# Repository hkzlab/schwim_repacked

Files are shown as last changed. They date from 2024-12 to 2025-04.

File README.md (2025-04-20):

# SCHWIM Repacked

## DISCLAIMER

Any use of this project is **under your own responsibility**.
You will be responsible of checking the correct construction and functionality of your board.
By using this project You will agree that I cannot be held responsible if it will destroy any of your devices, damage your computer, burn down your house or whatever.

## Introduction

This board is a SMD-based "replacement" of the (S)IWM for old Macintosh Computers, and is based on the work by [DosFox](https://github.com/DosFox1/Shim-IWM), of which it is just a repackaging in different format.

It implements enough of the logic to pass the initial boot check and allow the computer to continue booting. Floppy drive will not be functional. It is designed to fit in the same space as the original IC.

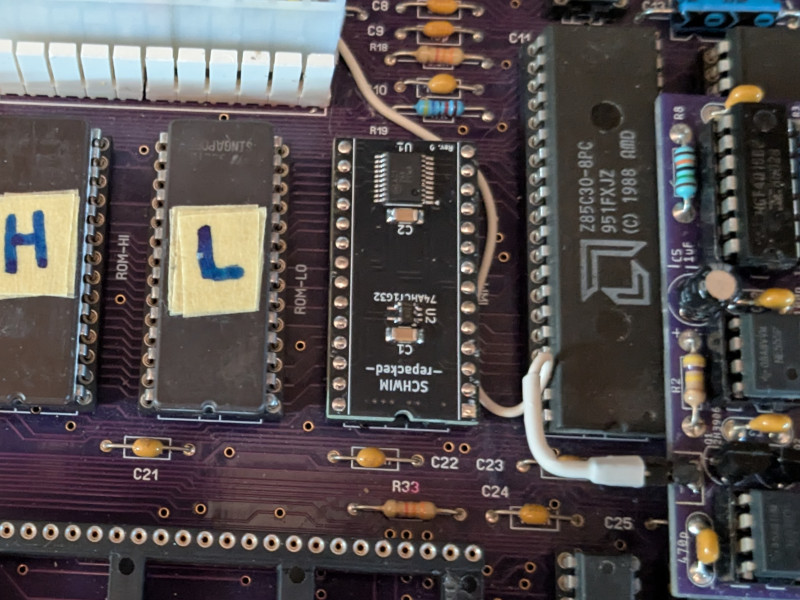
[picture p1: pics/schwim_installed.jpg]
Rev. 0 Board installed in a Mac Plus clone


## Hardware

The board was designed with [KiCad](https://kicad.org/) EDA.

### Bill of Materials

| Component | Qty | Type / Value | Notes |
| --- | --- | --- | --- |
| C1, C2 |  2  | 100nF / 1206 / ceramic | |
| U1 |  1  | 74HCT244 | TSSOP-20 |
| U2 |  1  | 74AHCT1G32 | SOT-23 |
| RN1, RN2 |  2  | 4x4.7K isolated resistor array | 4x0612 (1206 package) |
| pins |  2  | 14pin machined strips | Solder these as pins of the replaced IC on the underside, if you find long enough pins, you can insert them from above, solder them, then snip the top away for a lower profile build |  

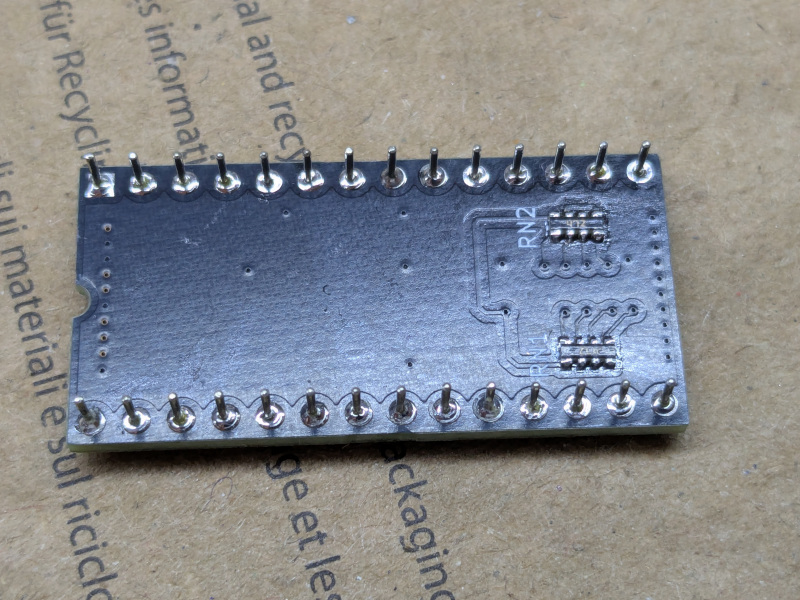
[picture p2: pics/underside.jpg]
Rev. 0 Board built with low profile headers


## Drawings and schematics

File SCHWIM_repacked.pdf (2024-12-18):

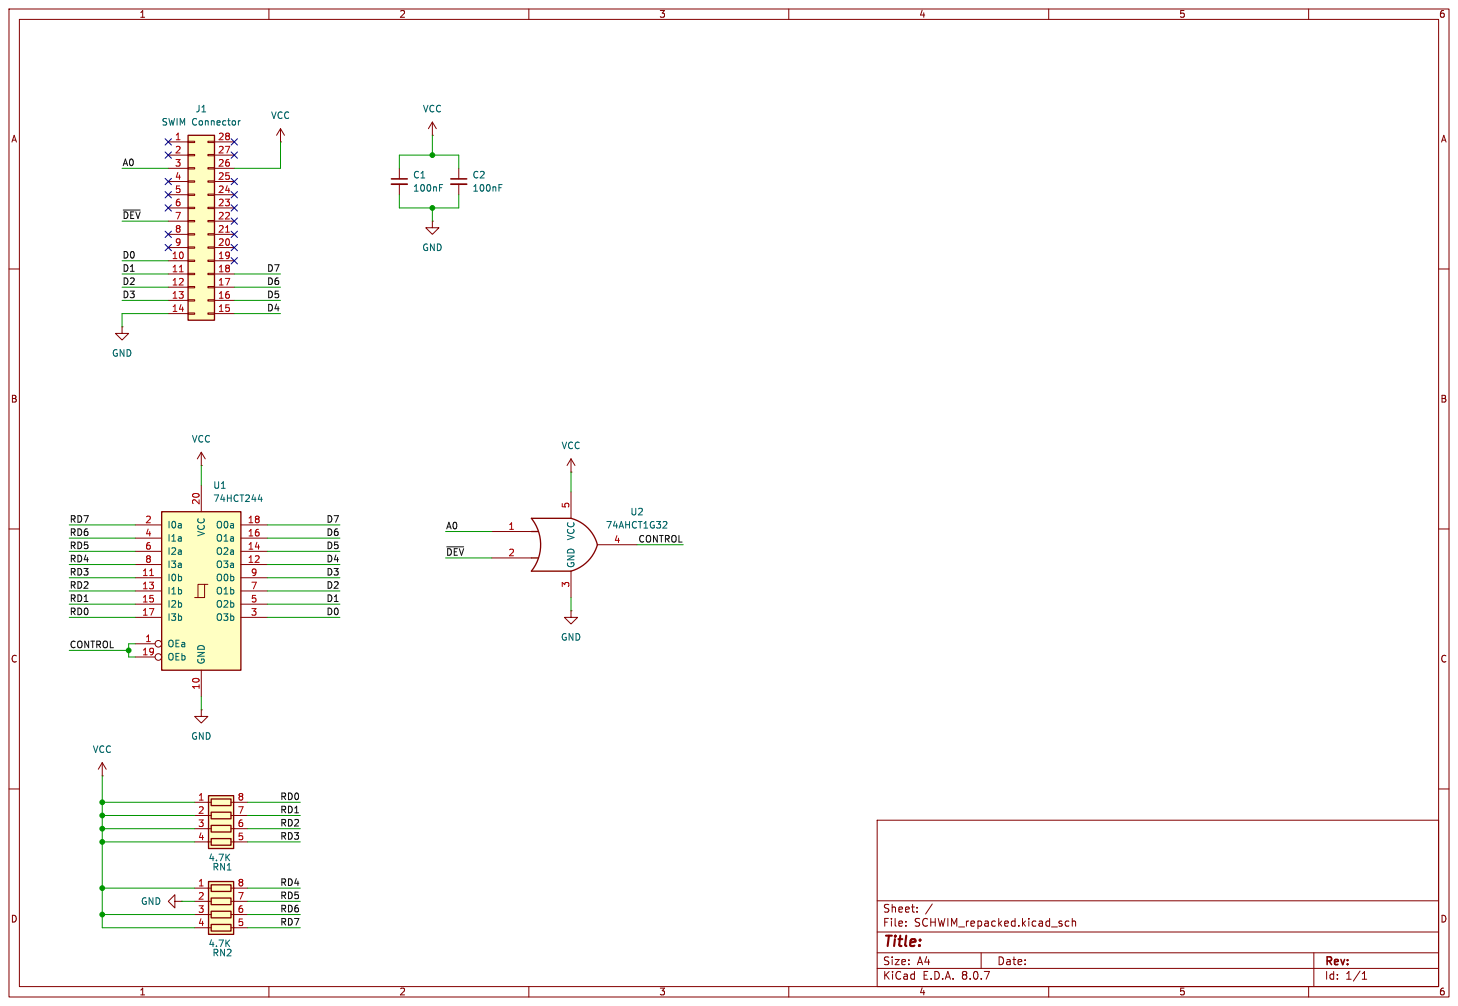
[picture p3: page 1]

Id: 1/1 Title: File: SCHWIM_repacked.kicad_sch Sheet: /

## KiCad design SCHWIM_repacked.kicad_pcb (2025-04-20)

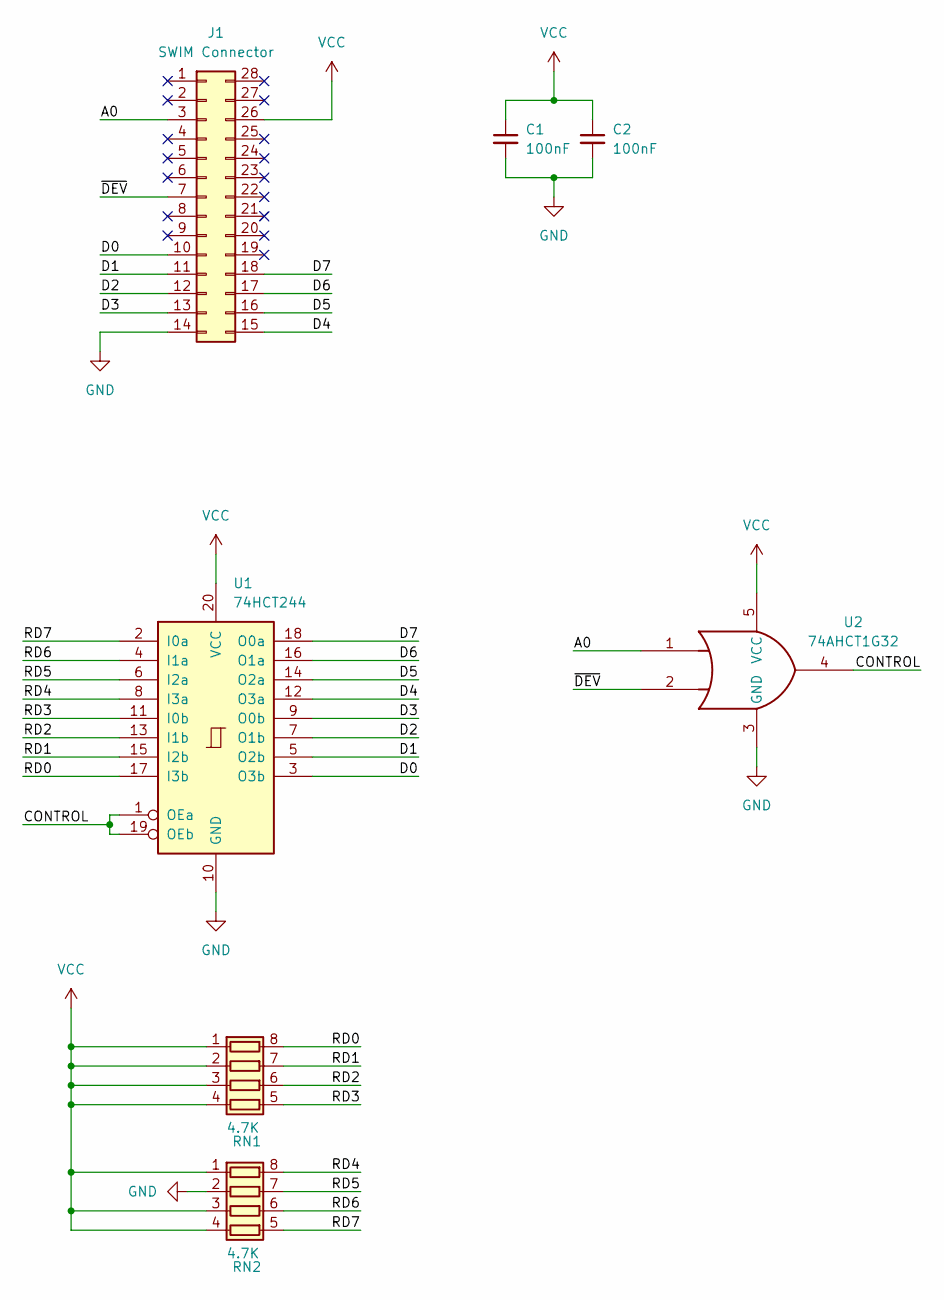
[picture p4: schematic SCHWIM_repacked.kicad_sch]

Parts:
C1, C2: 100nF; C_1206_3216Metric_Pad1.33x1.80mm_HandSolder
J1: SWIM Connector; DIP-28_W15.24mm_Socket
RN1, RN2: 4.7K; R_Array_Convex_4x0612
U1: 74HCT244; TSSOP-20_4.4x6.5mm_P0.65mm
U2: 74AHCT1G32; SOT-23-5_HandSoldering

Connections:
/A0: J1.3, U2.1
/CONTROL: U1.1 (OEa), U1.19 (OEb), U2.4
/D0: J1.10, U1.3 (O3b)
/D1: J1.11, U1.5 (O2b)
/D2: J1.12, U1.7 (O1b)
/D3: J1.13, U1.9 (O0b)
/D4: J1.15, U1.12 (O3a)
/D5: J1.16, U1.14 (O2a)
/D6: J1.17, U1.16 (O1a)
/D7: J1.18, U1.18 (O0a)
/RD0: RN1.8 (R1.2), U1.17 (I3b)
/RD1: RN1.7 (R2.2), U1.15 (I2b)
/RD2: RN1.6 (R3.2), U1.13 (I1b)
/RD3: RN1.5 (R4.2), U1.11 (I0b)
/RD4: RN2.8 (R1.2), U1.8 (I3a)
/RD5: RN2.7 (R2.2), U1.6 (I2a)
/RD6: RN2.6 (R3.2), U1.4 (I1a)
/RD7: RN2.5 (R4.2), U1.2 (I0a)
/~DEV: J1.7, U2.2
GND: C1.2, C2.2, J1.14, RN2.2 (R2.1), U1.10 (GND), U2.3 (GND)
VCC: C1.1, C2.1, J1.26, RN1.1 (R1.1), RN1.2 (R2.1), RN1.3 (R3.1), RN1.4 (R4.1), RN2.1 (R1.1), RN2.3 (R3.1), RN2.4 (R4.1), U1.20 (VCC), U2.5 (VCC)

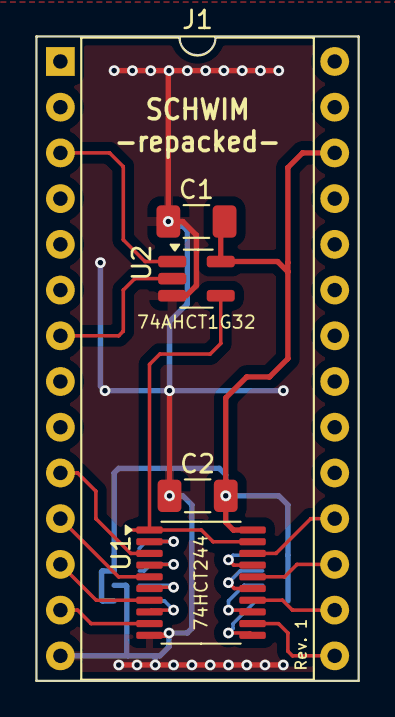
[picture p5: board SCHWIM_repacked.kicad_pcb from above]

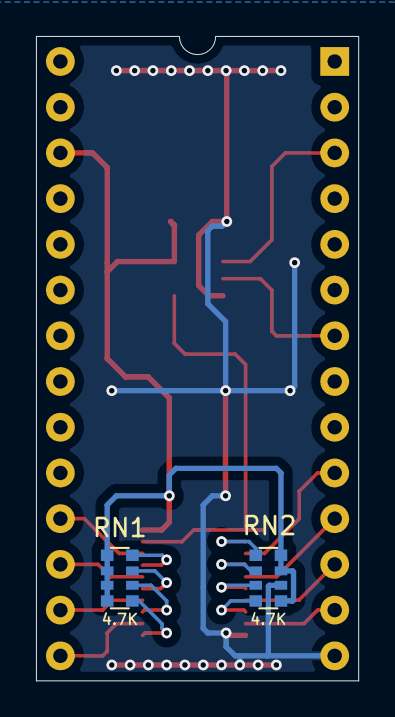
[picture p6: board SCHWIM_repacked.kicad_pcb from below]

Board: 2 copper layers, 17.9 x 35.8 mm, 7 parts (2 on the bottom side), 21 nets.

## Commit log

2024-11-01 Add shwim repacked
    [SCHWIM_repacked.kicad_pcb, SCHWIM_repacked.kicad_sch]
2024-11-10 Use a single or gate
    [SCHWIM_repacked.kicad_pcb, SCHWIM_repacked.kicad_sch]
2024-12-18 Updated schematics
2025-04-20 Added rev.1 of the repacked schwim, fixed footprint for U2
    [SCHWIM_repacked.kicad_pcb, SCHWIM_repacked.kicad_sch]
